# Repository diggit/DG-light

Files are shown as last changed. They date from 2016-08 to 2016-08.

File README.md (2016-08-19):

# DG-light

Lightweight module to iluminate various flying discs. (frisbee, DiscGolf,...? )

## Hardware

Kept simple and lightweight as possible. Only: MCU, leds, button, passives.
- **MCU**: **ATMEGA8A**
- **LEDs**:
 - 16x 5mm edge oriented LEDs
 - 1x SMD status LED
- **Buttons**:
 - user button (all settings)
 - reset button (wake from power off)

## V1
Proof of concept. Partialy worked.
### problems:
- **SW**: needed recalibration often (changing surfaces like: grass and asphalt caused capacity changes)
- **HW**:
 - missing charging port 
 - missing battery connect jumper
 - ISP inder battery
*sensitive to palm under electronics -> used as another control element (reset after pickup)*

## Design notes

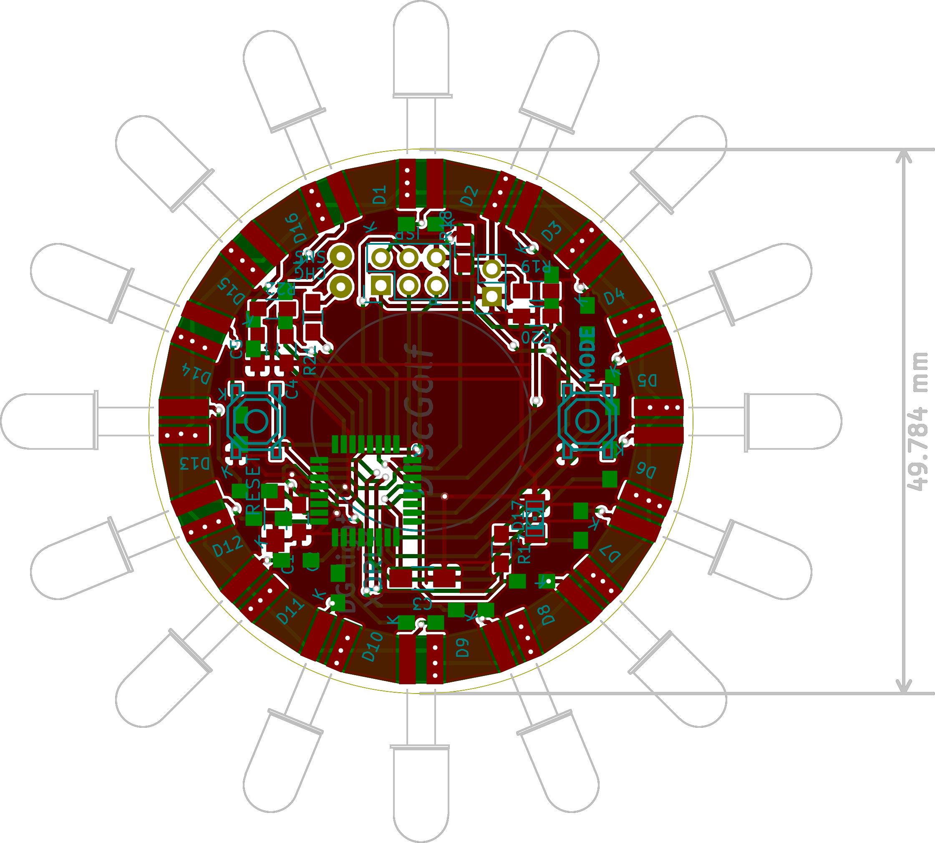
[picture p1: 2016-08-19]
hardware/board.png

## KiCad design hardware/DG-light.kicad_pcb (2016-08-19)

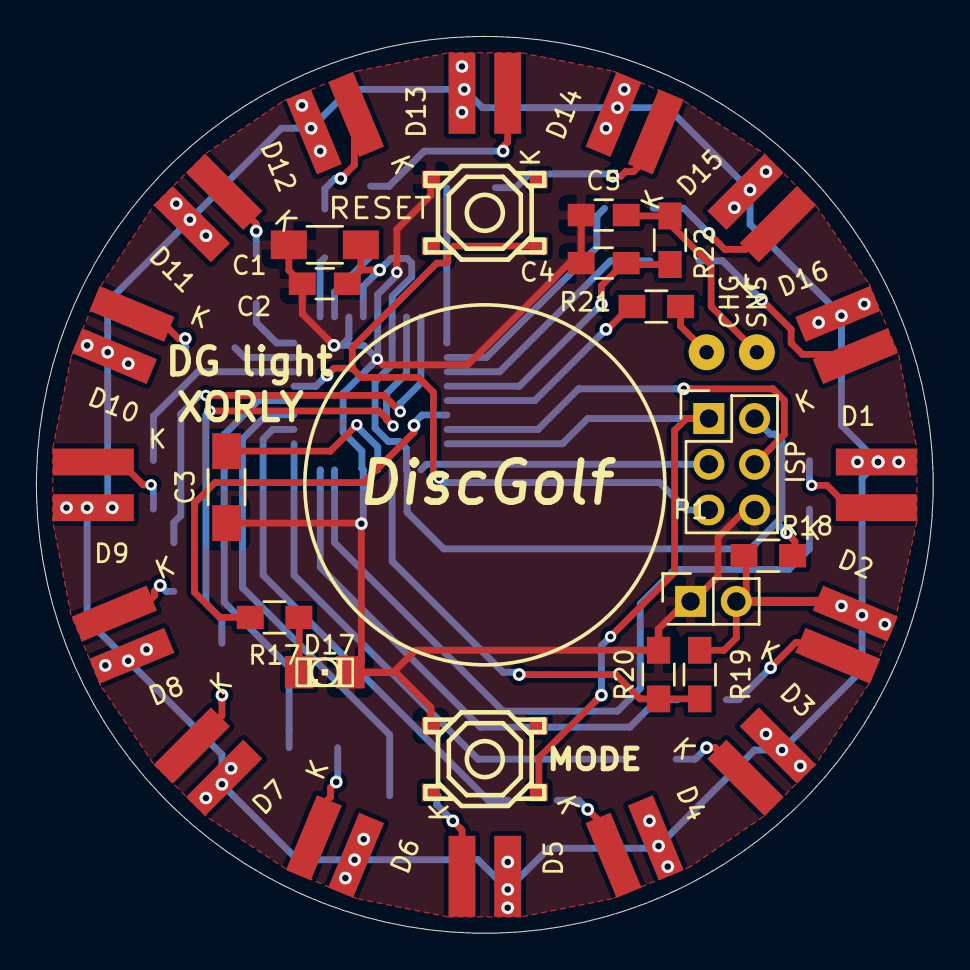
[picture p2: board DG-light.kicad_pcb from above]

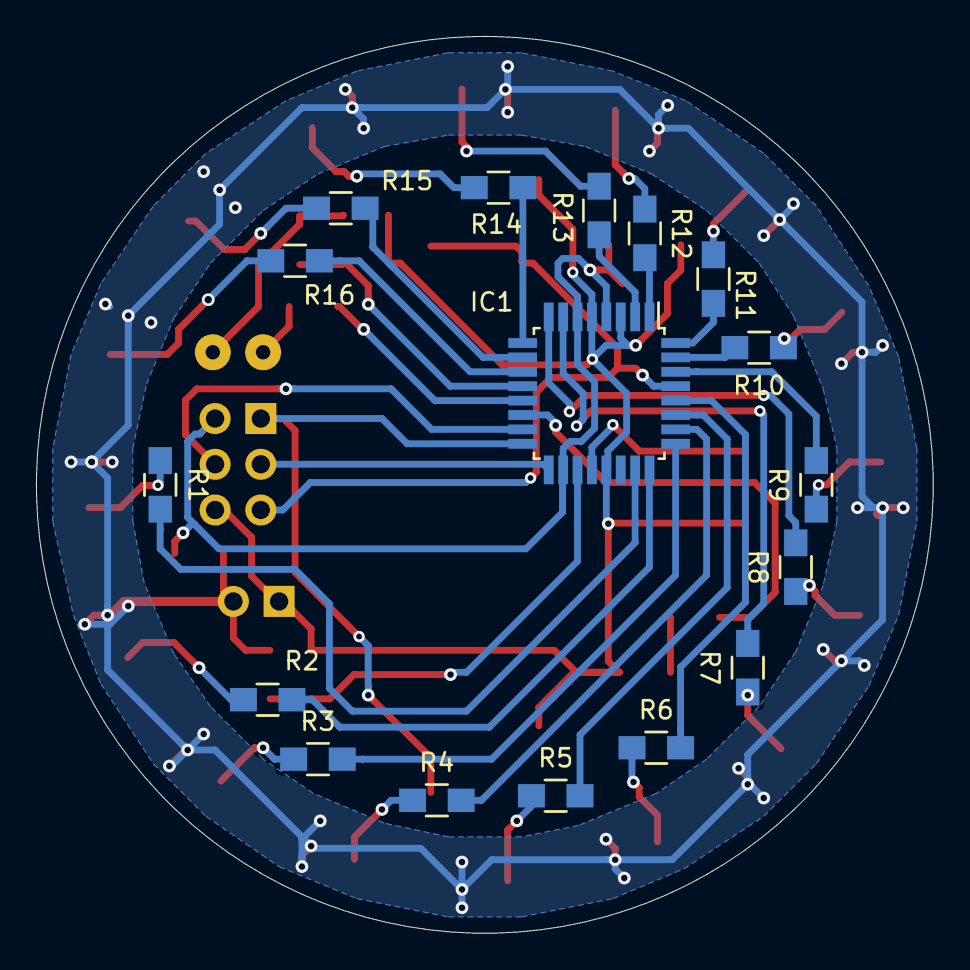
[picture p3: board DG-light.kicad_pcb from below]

Board: 2 copper layers, 49.8 x 49.8 mm, 51 parts (17 on the bottom side), 47 nets.

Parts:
C1, C3: C; C_1206_HandSoldering
C2, C4, C5: C; C_0805_HandSoldering
CHG: C_CHARGE; SolderWirePad_single_0-8mmDrill
D1, D2, D3, D4, D5, D6, D7, D8, D9, D10, D11, D12, D13, D14, D15, D16: LED; LED-5MM-SMD
D17: LED; LED-1206
IC1: ATMEGA8-AI; TQFP-32_7x7mm_Pitch0.8mm
ISP: ISP; Pin_Header_Straight_2x03
P1: PWR; Pin_Header_Straight_2x01
R1, R2, R3, R4, R5, R6, R7, R8, R9, R10, R11, R12, R13, R14, R15, R16, R17, R18, R21, R22: R; R_0805_HandSoldering
R19: R_SNS_HIGH; R_0805_HandSoldering
R20: R_SNS_LOW; R_0805_HandSoldering
SNS: C_SNS; SolderWirePad_single_0-8mmDrill
SW1: MODE; smd_push2
SW2: RESET; smd_push2

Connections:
+BATT: D1.1, D2.1, D3.1, D4.1, D5.1, D6.1, D7.1, D8.1, D9.1, D10.1, D11.1, D12.1, D13.1, D14.1, D15.1, D16.1, P1.2, R18.2, R19.2
C_SNS: C4.1, IC1.12, R22.2
GND: C1.2, C2.2, C3.1, C4.2, C5.2, D17.2, IC1.3, IC1.5, IC1.21, ISP.6, P1.1, R20.1, SW1.1, SW2.1
unnamed: C3.2, IC1.20
unnamed: C5.1, R22.1, SNS.1
unnamed: D1.2, R1.1
unnamed: D2.2, R2.1
unnamed: D3.2, R3.1
unnamed: D4.2, R4.1
unnamed: D5.2, R5.1
unnamed: D6.2, R6.1
unnamed: D7.2, R7.1
unnamed: D8.2, R8.1
unnamed: D9.2, R9.1
unnamed: D10.2, R10.1
unnamed: D11.2, R11.1
unnamed: D12.2, R12.1
unnamed: D13.2, R13.1
unnamed: D14.2, R14.1
unnamed: D15.2, R15.1
unnamed: D16.2, R16.1
unnamed: D17.1, R17.1
unnamed: IC1.1, R12.2
unnamed: IC1.2, R13.2
unnamed: IC1.7, R7.2
unnamed: IC1.8, R8.2
unnamed: IC1.9, R14.2
unnamed: IC1.10, R15.2
unnamed: IC1.11, R16.2
unnamed: IC1.13, R21.2
unnamed: IC1.14, R17.2
unnamed: IC1.15, ISP.4
unnamed: IC1.16, ISP.1, SW1.2
unnamed: IC1.17, ISP.3
unnamed: IC1.23, R1.2
unnamed: IC1.24, R2.2
unnamed: IC1.25, R3.2
unnamed: IC1.26, R4.2
unnamed: IC1.27, R5.2
unnamed: IC1.28, R6.2
unnamed: IC1.30, R9.2
unnamed: IC1.31, R10.2
unnamed: IC1.32, R11.2
unnamed: CHG.1, R21.1
RST: IC1.29, ISP.5, SW2.2
VCC: C1.1, C2.1, IC1.4, IC1.6, IC1.18, ISP.2, R18.1
V_SNS: IC1.19, R19.1, R20.2

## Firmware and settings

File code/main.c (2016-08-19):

#include <avr/io.h>
#include <inttypes.h>
#include <avr/interrupt.h>

#include "config.h"
#include "misc.h"
#include "storage.h"
#include "animation.h"
#include "menu.h"
#include "touch.h"
#include "button.h"
// #include "uart.h"

config_t config={0,0,0,100,0,0};

volatile status_t status=IDLE;


int main(void)
{
	uint8_t arm_lvl=0;
	touch_status_t local_touch;

	DDRC=PORTC_LEDS|POTRC_OUTS;
	DDRB=PORTB_LEDS|PORTB_OUTS;
	DDRD=PORTD_LEDS|PORTD_OUTS;
	PORTB|=(1<<BTN_PIN);
	flush_ex(0);
	STATUS_LED_OFF();

	sei();

	button_init();

	touch_init();

	if(bit_get(PINB,(1<<BTN_PIN))!=BTN_ACTIVE)
		storage_all_load();
	else
		storage_all_store();//store defaults

	while(1)
	{
		local_touch=touch_status;//create local copy to keep state same during whole cycle

		if( bit_get(btn,FLAG_HOLD) && status!=MENU)
		{
			status=MENU;
			menu_selected=0;
			bit_clr(btn,FLAG_HOLD);
			animation_clear();
			flush_ex(rotate_ex(1<<(menu_selected),MENU_OFFSET));
		}

		switch(status)
		{
			case IDLE:
				if((local_touch==PALM && config.arm_by_palm) || local_touch==GRIP)
				{
					arm_lvl++;

					delay_ms(50);
					if(arm_lvl==16)
					{
						status=ARMED;
						animation_set(&animations_ground[0]);
					}
				}
				else
				{
					arm_lvl=0;
				}
				flush_ex( FILL_BITS_FROM_LSB(arm_lvl) );
				break;

			case ARMED:
				switch(local_touch)
				{
					case FREE:
						animation_set(&animations_flight[config.animation]);
						gptimer=1;
						status=ANIMATING;
						break;
					case PALM:
						animation_clear();
						status=IDLE;
						break;

					default:
						break;
				}
				break;

			case ANIMATING:
				if(gptimer>=config.flight_length*FLIGHT_LENGTH_MULTIPLIER || local_touch==PALM) //grass touch is same as PALM touch...
				{
					gptimer=0;
					arm_lvl=0;
					animation_set(&animations_ground[1]);
					status=FIND_ME;
				}
				break;

			case MENU:
				if(menu_handler)
				{
					menu_handler();
				}
				else
				{
					STATUS_LED_ON();
					if(button_read_click())
					{
						if(menu_selected<15 && menu[menu_selected+1].handler_func!=NULL )
							menu_selected++;
						else
							menu_selected=0;
					}
					flush_ex(rotate_ex(1<<(menu_selected),MENU_OFFSET));

					if(button_read_hold())
					{
						if(menu[menu_selected].handler_func)
						{
							STATUS_LED_OFF();
							menu[menu_selected].handler_func();
						}
					}
					// if(menu_handler==NULL)//when menu handler was set just now, don't draw, it's up to him...

				}
				break;

			case FIND_ME://find me animation could be stopped by GRIP touch only
				if(local_touch==GRIP)
				{
					arm_lvl++;
					delay_ms(30);
					if(arm_lvl==16)
					{
						status=PICKED_UP;
						animation_set(&animations_ground[3]);

					}
				}
				else
				{
					arm_lvl=0;
				}
				break;

			case PICKED_UP://step between FIND_ME and ARMED, because both have same trigger (grip touch)
				if(local_touch==PALM)
				{
					status=IDLE;
					animation_clear();
				}
				break;



		}
		if(status==IDLE)// || status==ARMED || status== IDLE)
			delay_ms(1);//if IDLE has no delay, STATUS light blink is not regular, IDK WHY!

		if (animation!=NULL)
		{
			animation->process();
			delay_ms(animation->time_step);
		}
	}

}

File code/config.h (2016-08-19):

#ifndef _CONFIG
	#define _CONFIG

	#include <avr/io.h>
	#include <inttypes.h>

	#define ID	0x15


	//freq of MCU clocking
	#define FOSC 8000000UL
	//
	// #define BAUD 9600UL
	// #define UART_TX
	// #define UART_RX
	// #define UART_RX_INT_EN

	#define PORTC_LEDS ((1<<0)|(1<<1)|(1<<2)|(1<<3)|(1<<4)|(1<<5))
	#define POTRC_OUTS 0
	#define PORTB_LEDS ((1<<6)|(1<<7))
	#define PORTB_OUTS ((1<<1)|(1<<2))
	#define PORTD_LEDS (0xFF)
	#define PORTD_OUTS 0

	typedef struct{
		uint32_t cap_min;
		uint32_t cap_grip;
		uint32_t cap_palm;
		uint8_t flight_length;
		uint8_t	animation;
		uint8_t arm_by_palm:1;//otherwise grip will arm animation
	} config_t;
	typedef enum {IDLE,ARMED,ANIMATING,MENU,FIND_ME,PICKED_UP} status_t;

	extern volatile status_t status;

	#define FLIGHT_LENGTH_MULTIPLIER	32

	#define MENU_OFFSET 8

	extern config_t config;

#endif
